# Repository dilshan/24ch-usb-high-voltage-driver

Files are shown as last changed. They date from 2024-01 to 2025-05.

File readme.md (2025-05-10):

## 24-Channel USB high voltage driver

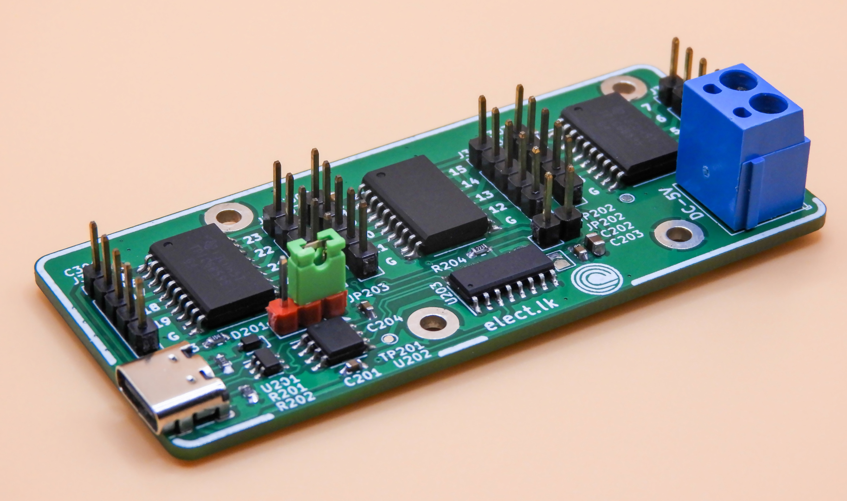
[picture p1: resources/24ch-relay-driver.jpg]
Prototype build of the 24-channel USB high voltage driver.


This project is a compact, driver-free USB module designed for high-voltage, medium-current output. It emphasizes ease of use, reliability, and flexibility for various control and automation applications. This module offers the following features:

- **24 independent high-voltage outputs:** Each output channel is controlled using [TPIC6B595](https://www.ti.com/lit/ds/symlink/tpic6b595.pdf) shift registers, which provide the capability for high-voltage and medium-current switching.

- **Dual power options:** Can choose between USB bus power and an external 5V supply using on-board jumpers.

- **Simple serial interface:** Communicate with the module through a virtual COM port using AT-style commands. You can easily set, get, and clear output states.

- **Device driver-free operation:** The module is recognized as a standard USB serial device (based on [CH340N](https://aitendo3.sakura.ne.jp/aitendo_data/product_img/ic/inteface/CH340N/ch340n.pdf)), meaning it requires no additional driver installation on most operating systems.

This repository includes the [schematic](https://github.com/dilshan/24ch-usb-high-voltage-driver/blob/main/design/24-ch-relay-driver-kicad.pdf), PCB design, firmware source code, and [compiled firmware](https://github.com/dilshan/24ch-usb-high-voltage-driver/releases) for this project. The complete [documentation](https://github.com/dilshan/24ch-usb-high-voltage-driver/wiki) for this project is available in the [wiki section](https://github.com/dilshan/24ch-usb-high-voltage-driver/wiki) of this repository. It includes all necessary details for producing the PCB, compiling and uploading the firmware, the command set, and more.

This is a [certified open-source hardware project](https://certification.oshwa.org/lk000015.html). All the design files, [documentation](https://github.com/dilshan/24ch-usb-high-voltage-driver/wiki), firmware source code are available to download at the project source repository. All the content of this project are distributed under the terms of the following license:

 - Hardware license: [CERN-OHL-W](https://opensource.org/license/cern-ohl-w)
 - Software license: [MIT License](https://github.com/dilshan/24ch-usb-high-voltage-driver/blob/main/LICENSE)
 - [Documentation](https://github.com/dilshan/24ch-usb-high-voltage-driver/wiki) license: [CC BY 4.0](https://creativecommons.org/licenses/by/4.0)
 
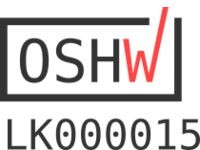
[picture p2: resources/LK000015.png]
LK000015 (https://certification.oshwa.org/lk000015.html)


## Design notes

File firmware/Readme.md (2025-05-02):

## 24-Channel USB driver - Serial communication interface

Serial  configuration  =  Baud:`9600` - 8N1

All commands execute after host terminal send the *carriage return*.

----

*ON=**RELAY_POSITIONS**

On relays at given positions. 
ex: `ON=5` : On relays at 1 and 4 positions.

Result: OK/FAIL

----
  
*OFF=**RELAY_POSITIONS**

Off relays at given positions. 
ex: `OFF=3` : Off relays at 1 and 2 positions.

Result: OK/FAIL

----  

*GET*

Return positions of the active relays.

Result: **RELAY_POSITIONS**. 
ex: `128`

----

*TOG=**RELAY_POSITIONS*** 

Toggle the output of the given position.
ex: `TOG=3` : Toggle relays at 1 and 2 positions.

Result: OK/FAIL

----

*CLR*

Clear and turn off all relay positions.

Result: OK/FAIL

----

*STR*

Store current relay position as default configuration.

Result: OK/FAIL

----

*VER*

Return firmware version and signature.

Result: `ELECT10`

----

* Input  buffer  size  (max): OFF=xxxxxxxx : **14**
* Output  buffer  size  (max): **10**

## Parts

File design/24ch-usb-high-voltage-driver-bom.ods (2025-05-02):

Reference | Value | Datasheet | Package | Qty | Sourcing
C201,C202,C204,C301,C302,C303 | 0.1MFD/16V |  | SMD 0603 | 6 | https://s.click.aliexpress.com/e/_omW5j1r
C203 | 1MFD/16V |  | SMD 0603 | 1 | https://s.click.aliexpress.com/e/_omW5j1r
D201 | BAT60A | https://www.infineon.com/dgdl/Infineon-BAT60ASERIES-DS-v01_01-en.pdf?fileId=db3a304313d846880113def70c9304a9 | SMD SOD-323 | 1 | https://s.click.aliexpress.com/e/_omLLIcp
J201 | USB Type-C 16-pin connector |  |  | 1 | https://s.click.aliexpress.com/e/_onZsd1r
J202 | 5mm Screw Terminal 2-pin | https://irrorwxhqiillo5p.ldycdn.com/KF128-5.08-aidqkBpqKirRlkSrlkplnloj.pdf | KF128-5.08-2P | 1 | https://s.click.aliexpress.com/e/_omqGQgp
J301,J302,J303,J304,J305,J306 | 5-pin Male Pin Header |  | 2.54mm 1x05 2.54mm Pin Header | 6 | https://s.click.aliexpress.com/e/_olWdYez
JP202 | 2-pin Male Pin Header |  | 2.54mm 1x02 2.54mm Pin Header | 1 | https://s.click.aliexpress.com/e/_olWdYez
JP203 | 3-pin Male Pin Header |  | 2.54mm 1x03 2.54mm Pin Header | 1 | https://s.click.aliexpress.com/e/_olWdYez
R201,R202 | 5.1K |  | SMD 0603 | 2 | https://s.click.aliexpress.com/e/_oprWGjP
R203 | 150K |  | SMD 0603 | 1 | https://s.click.aliexpress.com/e/_oprWGjP
R204 | 22K |  | SMD 0603 | 1 | https://s.click.aliexpress.com/e/_oprWGjP
U201 | USBLC6-2SC6 | https://www.st.com/resource/en/datasheet/usblc6-2.pdf | SMD SOT-23-6 | 1 | https://s.click.aliexpress.com/e/_ok9DjHP
U202 | CH340N | https://aitendo3.sakura.ne.jp/aitendo_data/product_img/ic/inteface/CH340N/ch340n.pdf | SMD SOP-8 | 1 | https://s.click.aliexpress.com/e/_ooWQ2NF
U203 | STC15W204S | www.stcmicro.com/datasheet/STC15F2K60S2-en.pdf | SMD SOP-16 | 1 | https://s.click.aliexpress.com/e/_oC6FfWp
U301,U302,U303 | TPIC6B595DWR | https://www.ti.com/lit/gpn/tpic6b595 | SMD SOP-20 | 3 | https://s.click.aliexpress.com/e/_ooHKLPx

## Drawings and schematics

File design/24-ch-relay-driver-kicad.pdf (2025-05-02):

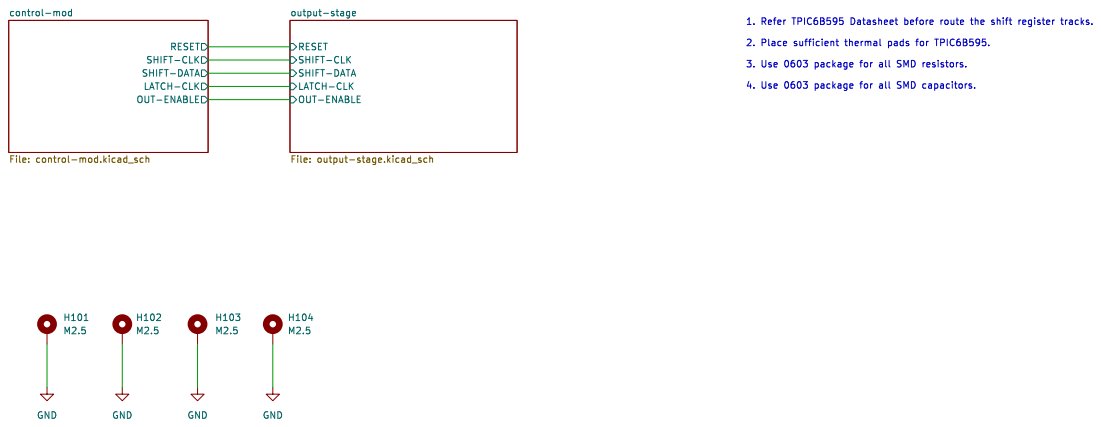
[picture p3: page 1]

SHIFT-DATA
LATCH-CLK OUT-ENABLE

https://github.com/dilshan/24ch-usb-high-voltage-driver
jayakody2000lk@gmail.com

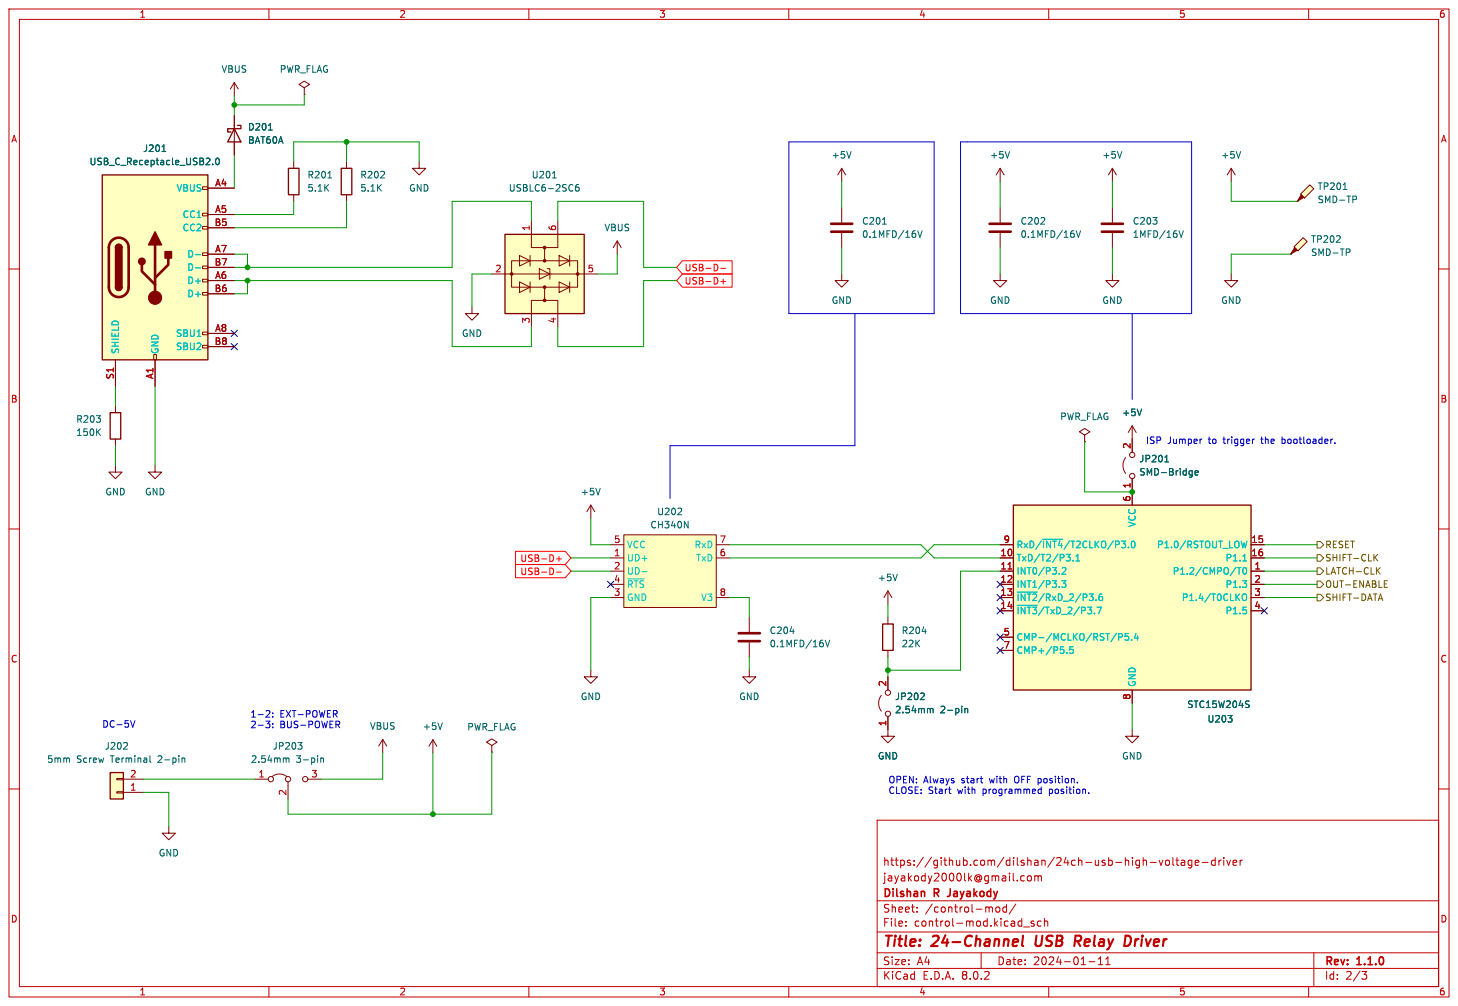
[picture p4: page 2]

5mm Screw Terminal 2-pin GND

https://github.com/dilshan/24ch-usb-high-voltage-driver GND

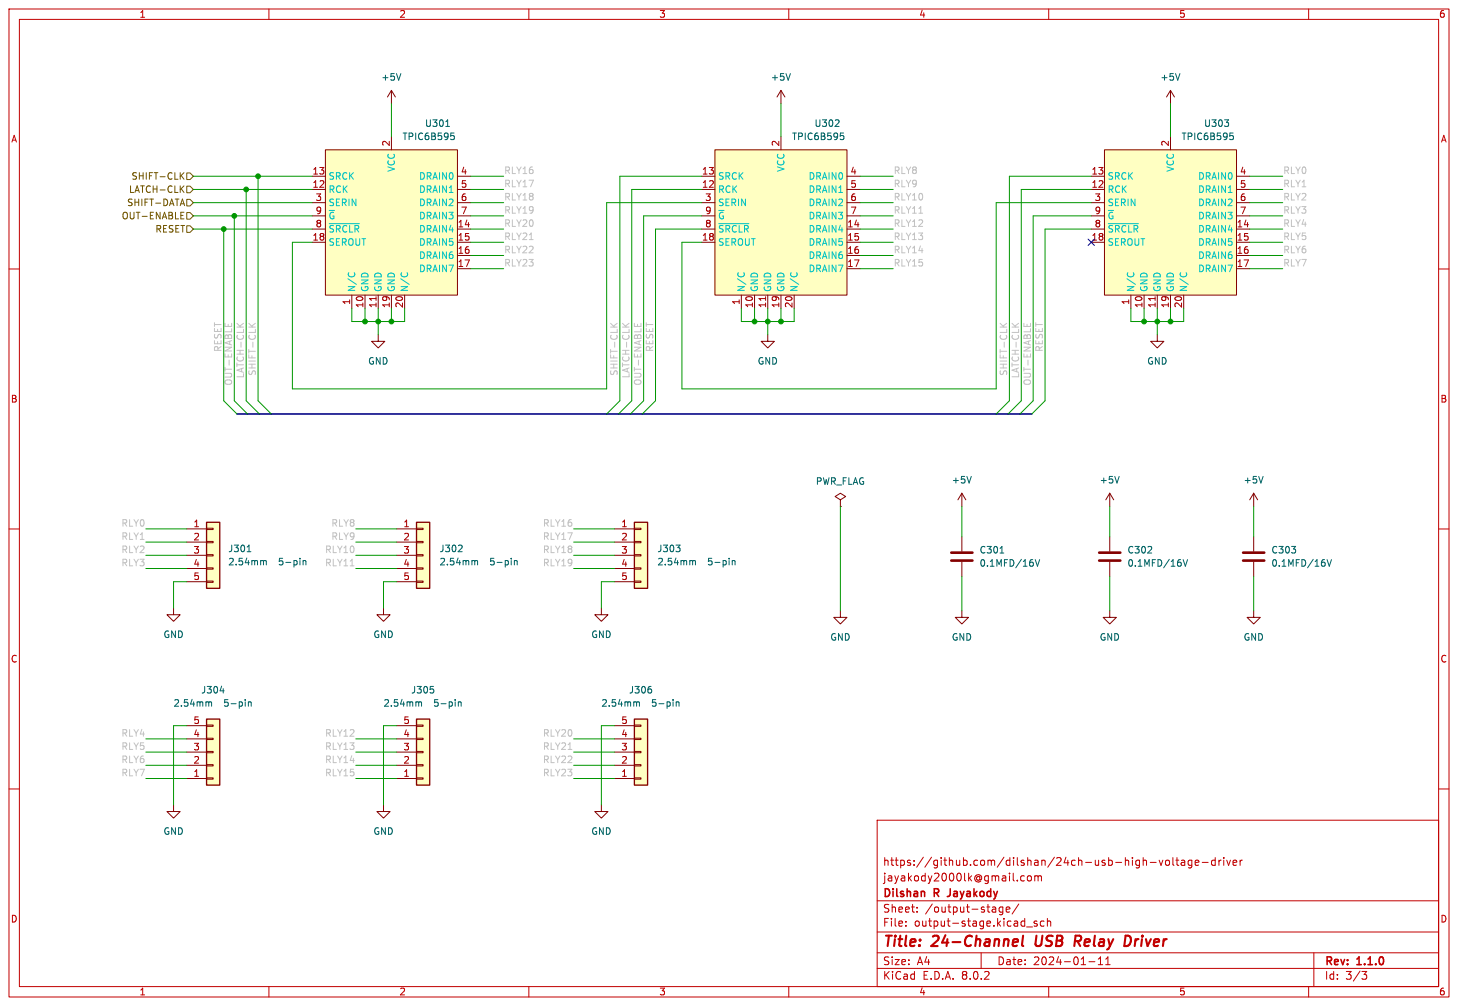
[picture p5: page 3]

1 GND 10 GND 11 RCK 12 SRCK 13 DRAIN4 14 DRAIN5 15 DRAIN6 16 DRAIN7 17 SEROUT 18 GND 19 VCC

SHIFT-CLK OUT-ENABLE

jayakody2000lk@gmail.com
R Jayakody USB Relay Driver File: output-stage.kicad_sch Sheet: /output-stage/ Dilshan Id: 3/3 Title: 24-Channel

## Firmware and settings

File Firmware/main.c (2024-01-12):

//-------------------------------------------------------------
// 24-Channel USB relay driver.
// 
// Last updated: Dilshan Jayakody [3rd Feb 2023]
//
// Update log:
// [03/02/2021] - Initial version - Dilshan Jayakody.
//-------------------------------------------------------------

#include "include/stc15.h"

#include "config.h"
#include "main.h"
#include "shiftreg.h"
#include "util.h"
#include "eeprom.h"

void UART_ISR(void) __interrupt(UART1_VECTOR) __using(1)
{
    IE &= ~(ES);

    if(SCON & RI)
    {
        // Receive interrupt flag has raised.
        SCON &= ~(RI);
        data = SBUF;

        // Ignore line feed character.
        if(data != 10)
        {
            if(data == 13)
            {
                // Execute command on carriage return.
                commandReady = 1;
            }        
            else if((rxDataPos < RX_BUFFER_SIZE) && (commandReady == 0))
            {
                // Fill command buffer.
                rxBuffer[rxDataPos++] = data;
            }
        }
    }

    if(SCON & TI)
    {
        // Transmit interrupt flag has raised.
        SCON &= ~(TI);

        if(txDataPos > 0)
        {
            SBUF = txBuffer[--txDataPos];
        }
    }

    IE |= ES;
}

// Main application entrypoint.
void main()
{	
	initSystem();

    // Free input data buffer.
    freeStr(rxBuffer, RX_BUFFER_SIZE);

    // Load default configuration based on jumper setting.
    if((P3 & 0x04) == 0x00)
    {
        // Load saved configuration from EEPROM and apply to output.
        output = loadValueFromEEPROM();
        updateOutput(&output);
    }

    // Main service loop.
    while(1)
    {
        if(commandReady)
        {
            outputReady = 0;
            tempOutput = 0;

            // Looking for ON or OFF command.
            if(rxBuffer[0] == 'O')
            {
                if((rxBuffer[1] == 'N') && (rxBuffer[2] == '='))
                {
                    // Received ON command from the host.
                    outputReady = strToLong((rxBuffer + 3), &tempOutput, RX_BUFFER_SIZE);

                    // Only up to 24 positions are allowed for ON commands.
                    if(tempOutput > MAX_IO_MASK)
                    {
                        outputReady = 0;
                    }
                    
                    tempOutput = tempOutput | output;
                }
                else if((rxBuffer[1] == 'F') && (rxBuffer[2] == 'F') && (rxBuffer[3] == '='))
                {
                    // Received OFF command from the host.
                    outputReady = strToLong((rxBuffer + 4), &tempOutput, RX_BUFFER_SIZE);

                    // Only up to 24 positions are allowed for OFF commands.
                    if(tempOutput > MAX_IO_MASK)
                    {
                        outputReady = 0;
                    }

                    tempOutput = output & (~tempOutput);
                }

                changeOutput();
            }
            else if((rxBuffer[0] == 'G') && (rxBuffer[1] == 'E') && (rxBuffer[2] == 'T'))
            {
                // Receive GET command from the host terminal.
                // Convert output value to string.
                txDataPos = longToStr(&output, txBuffer);
                txDataPos++;
                
                // Send message to the host terminal.                
                SCON |= TI;
            }
            else if((rxBuffer[0] == 'T') && (rxBuffer[1] == 'O') && (rxBuffer[2] == 'G') && (rxBuffer[3] == '='))
            {
                // Received TOG command from the host.
                outputReady = strToLong((rxBuffer + 4), &tempOutput, RX_BUFFER_SIZE);

                // Only up to 24 positions are allowed for OFF commands.
                if(tempOutput > MAX_IO_MASK)
                {
                    outputReady = 0;
                }

                tempOutput = tempOutput ^ output;
                changeOutput();
            }
            else if((rxBuffer[0] == 'C') && (rxBuffer[1] == 'L') && (rxBuffer[2] == 'R'))
            {
                // Receive CLR command from the host terminal.
                tempOutput = 0;
                outputReady = 1;
                changeOutput();
            }
            else if((rxBuffer[0] == 'S') && (rxBuffer[1] == 'T') && (rxBuffer[2] == 'R'))
            {
                // Receive STR command from the host terminal.
                saveValueToEEPROM(&output);

                // Save current relay terminal configuration into EEPROM.
                outputReady = 1;
                returnStatusMsg(&outputReady);
            }
            else if((rxBuffer[0] == 'V') && (rxBuffer[1] == 'E') && (rxBuffer[2] == 'R'))
            {
                // Receive VER command from the host terminal.
                returnVersion();
            }
            else
            {
                // Unknown command from the host terminal.
                returnStatusMsg(&outputReady);
            }

            // Free input data buffer.
            freeStr(rxBuffer, RX_BUFFER_SIZE);

            // Clear flags and reset counter to capture the next incoming command from the host.
            outputReady = 0;
            rxDataPos = 0;
            commandReady = 0;
        }
        else
        {
            // Commands are not available from host.
            delay10us();
        }
    }   
}

void changeOutput()
{
    // Check flag to change the relay output(s).
    if(outputReady)
    {
        // Update relay positions and status variable.
        tempOutput = tempOutput & MAX_IO_MASK;
        updateOutput(&tempOutput);
        output = tempOutput;
    }

    // Notify command status to the host terminal.
    returnStatusMsg(&outputReady);
}

void returnVersion()
{
    txBuffer[8] = 'E';
    txBuffer[7] = 'L';
    txBuffer[6] = 'E';
    txBuffer[5] = 'C';
    txBuffer[4] = 'T';
    txBuffer[3] = '1';
    txBuffer[2] = '0';

    txBuffer[1] = 10;
    txBuffer[0] = 13;
    txDataPos = 9; 

    // Send message to the host terminal.
    SCON |= TI;
}

void returnStatusMsg(unsigned char *status)
{
    if(*status)
    {
        // Send 'OK' if the status is TRUE.
        txBuffer[3] = 'O';
        txBuffer[2] = 'K';

        txBuffer[1] = 10;
        txBuffer[0] = 13;
        txDataPos = 4;        
    }
    else
    {
        // Send 'FAIL' if the status is FALSE.
        txBuffer[5] = 'F';
        txBuffer[4] = 'A';
        txBuffer[3] = 'I';
        txBuffer[2] = 'L';

        txBuffer[1] = 10;
        txBuffer[0] = 13;
        txDataPos = 6; 
    }

    // Send message to the host terminal.
    SCON |= TI;
}

void initSystem()
{
	// P1.0 [OUT] : Shift register - ~RESET
    // P1.1 [OUT] : Shift register - SHIFT-CLOCK
    // P1.2 [OUT] : Shift register - LATCH-CLOCK
    // P1.3 [OUT] : Shift register - ~OUTPUT-ENABLE
    // P1.4 [OUT] : Shift register - DATA
    P1M1 = 0x00;
    P1M0 = 0xFF;
    P1 = 0x08;

    // P3.0 [IN]  : Serial RxD.
    // P3.1 [OUT] : Serial TxD.
    // P3.2 [IN]  : Startup configuration jumper.
    P3M1 = P3M1 | 0x04;
    P3M0 = P3M0 & 0xFB;
    P3 = P3 | 0x04;

    // Stop TIMER2.
    AUXR &= ~(T2R);

    // Setup UART port as 9600-baud with 8N1. User TIMER2 as baud rate generator.
    AUXR1 &= ~(S1_S1 | S1_S0);
    SCON &= ~(SM0);
    SCON |= (SM1 | REN);
    AUXR |= S1ST2;                    

    // Set baud rate as 9600.
    T2L = 0xE0;
    T2H = 0xFE;
    AUXR &= ~(T2CT); 
    AUXR |= T2_12; 

    // Set interrupts related to UART.
    IP |= PS;                           
    SCON &= ~(TI | RI);                
    IE |= (EA | ES); 

    // Initialize global variables.
    rxDataPos = 0;
    txDataPos = 0;
    commandReady = 0;
    outputReady = 0;
    output = 0;

    // Start TIMER2 to activate the UART.
    AUXR |= T2R;

    // Start shift register from reset.
    P1 = 0x01;
}

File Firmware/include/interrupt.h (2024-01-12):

//-------------------------------------------------------------
// STC51 interrupt definition for SDCC.
// 
// Based on STC15series MCU Data Sheet - 2015/10/10.
// Last updated: Dilshan Jayakody [14th Jan 2021]
//
// Update log:
// [14/01/2021] - Initial version - Dilshan Jayakody.
//-------------------------------------------------------------

#ifndef STC15W_INTERRUPT_H
#define STC15W_INTERRUPT_H

#define INT0_VECTOR	            0   // External Interrupt 0.
#define	TIMER0_VECTOR	        1   // Timer 0 Interrupt.
#define	INT1_VECTOR		        2   // External Interrupt 1.
#define	TIMER1_VECTOR	        3   // Timer 1 Interrupt.
#define	UART1_VECTOR	        4   // UART1 Interrupt.
#define	ADC_VECTOR		        5   // ADC Interrupt.
#define	LVD_VECTOR		        6   // Low Voltage Detection (LVD) Interrupt.
#define	PCA_VECTOR		        7   // CCP/PWM/PCA Interrupt.
#define	UART2_VECTOR	        8   // UART2 Interrupt.
#define	SPI_VECTOR		        9   // SPI Interrupt.
#define	INT2_VECTOR		        10  // External Interrupt 2.
#define	INT3_VECTOR		        11  // External Interrupt 3.
#define	TIMER2_VECTOR	        12  // Timer 2 Interrupt.
#define PWM_VECTOR              13  // PWM Interrupt ? (Documentation or reference not available).
#define	INT4_VECTOR		        16  // External Interrupt 4.
#define	UART3_VECTOR	        17  // UART3 Interrupt.
#define	UART4_VECTOR	        18  // UART4 Interrupt.
#define	TIMER3_VECTOR	        19  // Timer 3 Interrupt.
#define	TIMER4_VECTOR	        20  // Timer 4 Interrupt.
#define	COMPRATOR_VECTOR		21  // Comparator Interrupt.

// Interrupt Enable Rsgister (IE) bit definitions.
#define EA      0x80    // Enable all interrupts.
#define ELVD    0x40    // Low volatge detection interrupt enable bit.
#define EADC    0x20    // ADC interrupt enable bit.
#define ES      0x10    // UART1 interrupt enable bit.
#define ET1     0x08    // Timer 1 interrupt enable bit.
#define EX1     0x04    // External interrupt 1 enable bit.
#define ET0     0x02    // Timer 0 interrupt enable bit.
#define EX0     0x01    // External interrupt 0 enable bit.

// Interrupt Enable Rsgister 2 (IE2) bit definitions.
#define ET4     0x40    // Timer 4 interrupt enable bit.
#define ET3     0x20    // Timer 3 interrupt enable bit.
#define ES4     0x10    // UART4 interrupt enable bit.
#define ES3     0x08    // UART3 interrupt enable bit.
#define ET2     0x04    // Timer 2 interrupt enable bit.
#define ESPI    0x02    // SPI interrupt enalbe bit.
#define ES2     0x01    // UART2 interrupt enable bit.

// Interrupt Priority Register (IP) bit definitions.
#define PPCA    0x80    // PCA interrupt priority control bit.
#define PLVD    0x40    // Low voltage detection interrupt priority control bit.
#define PADC    0x20    // ADC interrupt priority control bit.
#define PS      0x10    // UART1 interrupt priority control bit.
#define PT1     0x08    // Timer 1 interrupt priority control bit.
#define PX1     0x04    // External interrupt 1 priority control bit.
#define PT0     0x02    // Timer 0 interrupt priority control bit.
#define PX0     0x01    // External interrupt 0 priority control bit.

// Interrupt Priority Register 2 (IP2) bit definitions.
#define PSPI    0x02    // SPI interrupt priority control bit.
#define PS2     0x01    // UART2 interrupt priority control bit.

#endif /* STC15W_INTERRUPT_H */

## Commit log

2024-01-12 Add new Simtelic logo and update version.
    [24-ch-relay-driver-kicad.kicad_pcb, 24-ch-relay-driver-kicad.kicad_sch, control-mod.kicad_sch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]
2024-01-12 Add gerber files for production [12/01/2024]
    [24-ch-relay-driver-kicad-B_Cu.gbr, 24-ch-relay-driver-kicad-B_Mask.gbr, 24-ch-relay-driver-kicad-B_Paste.gbr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]
2024-05-05 Add initial version of documentation.
    [24-ch-relay-driver-kicad.kicad_pcb, el0001-driver-interface.kicad_pcb, el0001-driver-interface.kicad_sch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]
2025-05-02 Clean project directory to publish.
    [24-ch-relay-driver-kicad-B_Cu.gbr, 24-ch-relay-driver-kicad-B_Mask.gbr, 24-ch-relay-driver-kicad-B_Paste.gbr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]
2025-05-02 Upgrade schematic to new KiCAD version.
    [24-ch-relay-driver-kicad.kicad_pcb, 24-ch-relay-driver-kicad.kicad_sch, control-mod.kicad_sch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]
2025-05-02 Upgrade schematic to new SDCC version.
2025-05-02 Add PDF version of the schematic.
2025-05-02 Add project BoM.
    [24ch-usb-high-voltage-driver-bom.ods]
2025-05-03 Add photo of the prototype build.
2025-05-03 Update readme.md with prototype build photo.
2025-05-03 Add board layout drawing.
2025-05-03 Add schematics of sample interfaces.
    [sample-driver-interface.kicad_pcb, sample-driver-interface.kicad_sch, sample1.kicad_sch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]
2025-05-04 Add board dimensions.
